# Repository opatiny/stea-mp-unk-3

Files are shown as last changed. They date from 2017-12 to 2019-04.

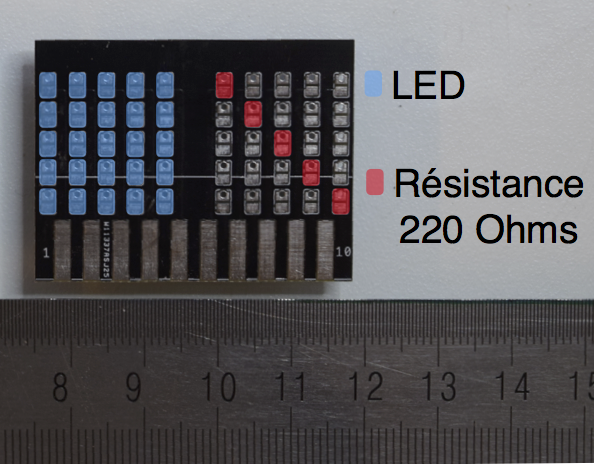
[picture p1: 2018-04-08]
docs/pics/ledMatrixPic.png

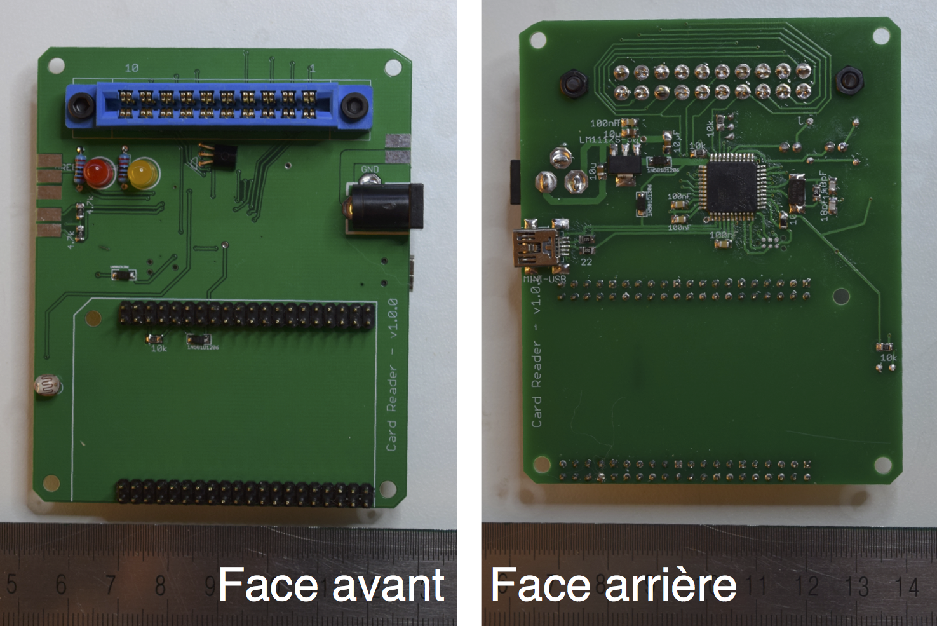
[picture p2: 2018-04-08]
docs/pics/cardReaderPic.png

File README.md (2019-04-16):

# stea-mp-unk-3
## Building an mp3 player in a steampunk style
The goal of this project is to build an autonomous mp3 player contained in an old leather suitcase. It works on batteries, has a 32 characters led display (home-made) and offers an oldschool way to chose the music to play: it uses perforated PCBs with a unique connectivity.

## Results
You can see the final player on this video (in french):
[https://youtu.be/DE0FV9JWbVA](https://youtu.be/DE0FV9JWbVA)

## Documentation
Sadly, the documentation to this project is written in french.
You can find a two-parts description of the project on the following links:

__Frist part: developing and producing the PCBs__

[https://oci.gyre.ch/blog/?post/2018/02/01/18H-patiny](https://oci.gyre.ch/blog/?post/2018/02/01/18H-patiny)

__Second part: finishing the project__

[https://oci.gyre.ch/blog/?post/2017/12/04/18P-patiny](https://oci.gyre.ch/blog/?post/2017/12/04/18P-patiny)

## Programming
All the code related to this project can be found [here](https://github.com/opatiny/node-steam-player).

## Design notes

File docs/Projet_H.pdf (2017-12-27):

# Construction d’un lecteur mp3 steampunk

### Océane Patiny

### 27 décembre 2017

## Description

L’objectif de ce projet est de réaliser un player mp3 dans un style steampunk, qui sera contenu dans une vieille valise. Le produit final sera muni de plusieurs haut-parleurs, d’un affichage LED contrôlé en I2C et il fonctionnera sur batteries. L’écran LED servira à afficher le titre et auteur de la musique ainsi que le temps restant jusqu’à la fin du morceau. La principale particularité sera néanmoins la technique utilisée pour choisir le morceau de musique à jouer. En effet, nous utiliserons des circuits imprimés ayant chacun une connectique unique qui correspond à un morceau. Les cartes devront être placées dans un connecteur de carte enfichable faisant partie d’un module I2C (que nous développerons). Sur ce module, un ATmega32U4 sera alors responsable de vérifier la connectivité. Cela fait, il attribuera celle-ci à un code unique qui pourra être envoyé par I2C à un CHIP. En effet, le micro-contrôleur central de ce projet sera un CHIP, qui est pratique pour sa sortie audio incorporée. Globalement, deux parties hardware devront être développées, étant les deux des modules I2C : premièrement, l’affichage LED, en second lieu, le lecteur de cartes. Ensuite, la partie software permettra le contrôle des modules que nous aurons construits, ainsi que la communication entre ceux-ci et le CHIP.

Élément de l’affichage led

Haut-parleur

PCB de lecture de carte

“Multi-prise”

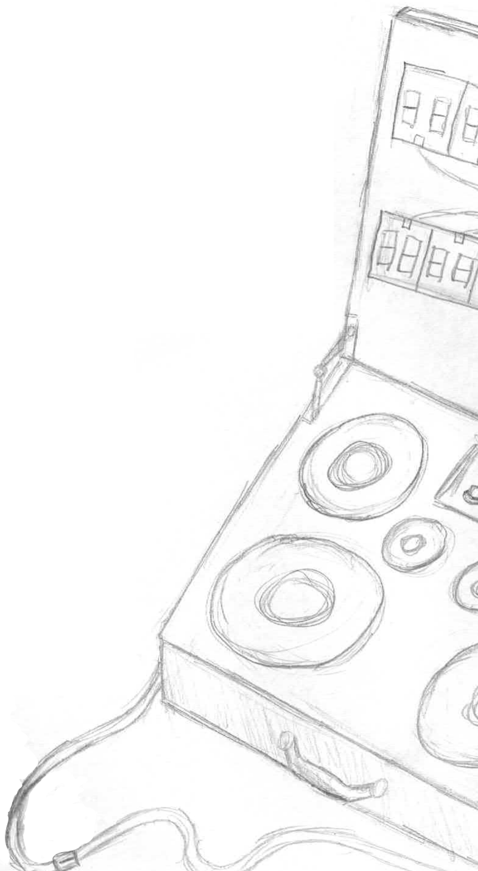
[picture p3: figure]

Figure 1: Schéma global de la valise.

Océane Patiny (3mp2)

## Matériel

Tout le matériel nécessaire à la réalisation de ce projet est listé ci-dessous. Il a été sub-divisé en trois groupes : le matériel que nous avons déjà à disposition, celui qu’il faut acheter et celui qu’il faut construire.

Disponible
— 1 vieille valise en cuir (dimensions intérieures : 450x315x100 mm) — Connecteurs rj12 et câble adapté
— 32 ULN2803
— 9 PCA9685
— 1 ATmega32U4
— 6 haut-parleurs

À se procurer
— 1 bouton rotatif (rotary button) — 1 interrupteur (push button)
— 1 amplificateur
— 7 PCA9685
— 256 résistances de au moins 1 kΩ
— 736 LEDs rouges 5 mm
— 1 connecteur de carte affichable de 10 pôles
— Résistances et condensateurs divers
— 1 batterie de 12 V puissante, par exemple une batterie de mobylette

À réaliser
— 1 PCB lecteur de cartes + bouton de volume + bouton d’allumage
— 16 PCB, chacun de 2 caractères lumineux
— 1 PCB faisant office de multiprise (hub) pour les connecteurs rj12 provenant des cartes de l’affichage LED
— Un modèle de PCB permettant de connecter différentes pattes de sortie de façon unique pour chaque carte. Le nombre de cartes variera en fonction du nombre de morceaux de musique désiré.

## Projet H : Objectifs février

Ce projet sera divisé en deux parties, la première se focalisant sur le hardware et la seconde sur le software. Un premier délai est imposé le 1er février 2018. À cette date, les objectifs suivants devront être remplis :

1. Accumuler le matériel électronique nécessaire à la réalisation du projet.
2. Réaliser des tests permettant de se familiariser avec la sortie son du CHIP.
3. Choisir le matériau à utiliser pour la fixation des hauts-parleurs et de l’affichage LED, acheter des peintures et vis si nécessaire.
4. Réaliser une première version de tous les PCB, les produire et les tester, repérer les bugs à corriger.
5. Choisir le type de support mémoire à utiliser pour stocker la musique.

Pour réussir l’objectif 4, le design des plaques devra être terminé au maximum pendant

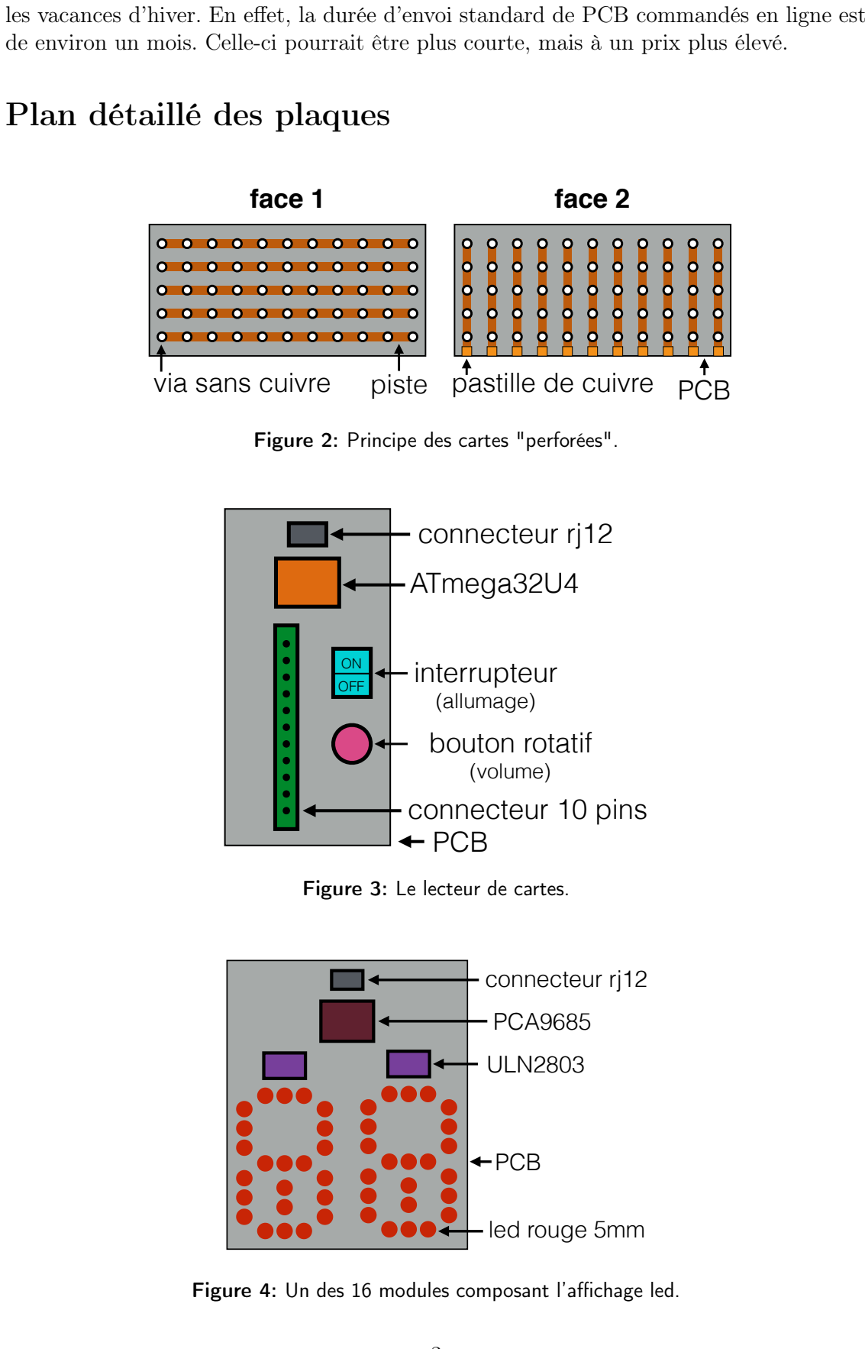
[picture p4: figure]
Plan détaillé des plaques; via sans cuivre; piste; face 1; PCB; face 2; pastille de cuivre; connecteur rj12; ATmega32U4; connecteur 10 pins PCB; OFF; interrupteur; (allumage) bouton rotatif (volume); Figure 3: Le lecteur de cartes.; PCA9685; ULN2803; led rouge 5mm

les vacances d’hiver. En effet, la durée d’envoi standard de PCB commandés en ligne est de environ un mois. Celle-ci pourrait être plus courte, mais à un prix plus élevé.

Figure 2: Principe des cartes "perforées".

Figure 4: Un des 16 modules composant l’affichage led.

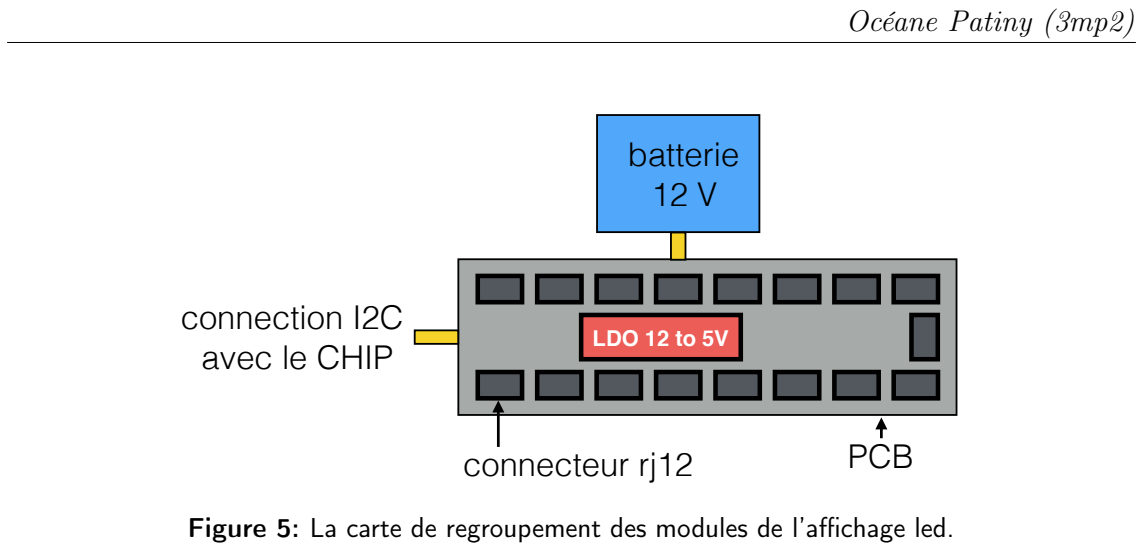
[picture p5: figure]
connection I2C avec le CHIP; batterie 12 V; LDO 12 to 5V; connecteur rj12; PCB

Figure 5: La carte de regroupement des modules de l’affichage led.

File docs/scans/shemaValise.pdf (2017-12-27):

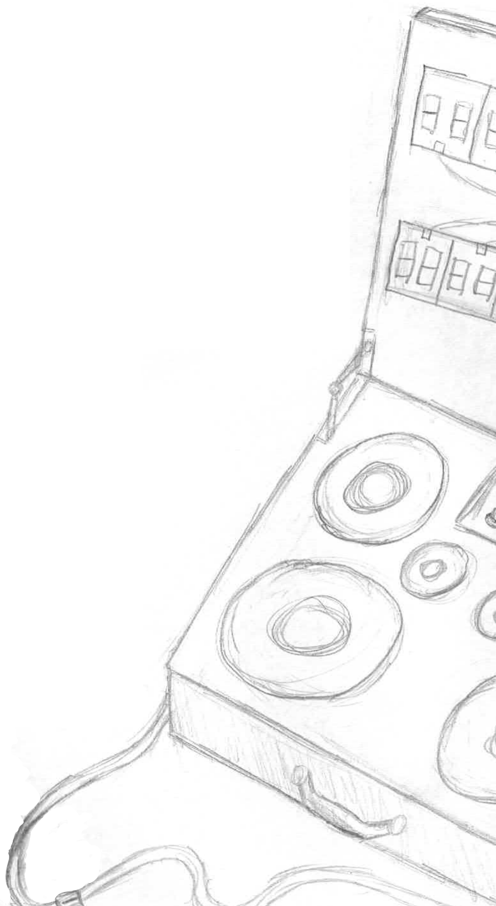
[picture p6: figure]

Élément de l’affichage led

Haut-parleur

PCB de lecture de carte

“Multi-prise”

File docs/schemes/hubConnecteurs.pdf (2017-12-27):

connection I2C
avec le CHIP

batterie
12 V

LDO 12 to 5V

connecteur rj12 | PCB

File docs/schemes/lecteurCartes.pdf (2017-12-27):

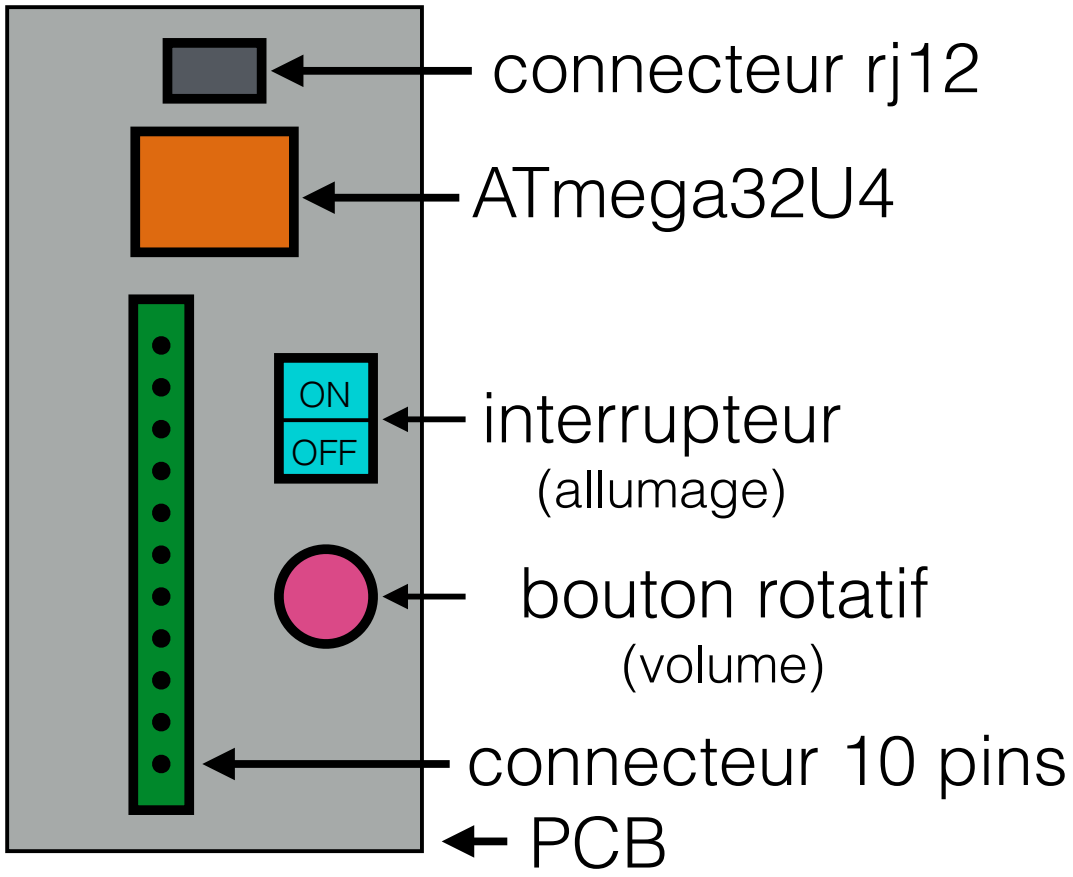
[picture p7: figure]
connecteur rj12; ATmega32U4; connecteur 10 pins PCB; OFF; interrupteur; (allumage) bouton rotatif (volume)

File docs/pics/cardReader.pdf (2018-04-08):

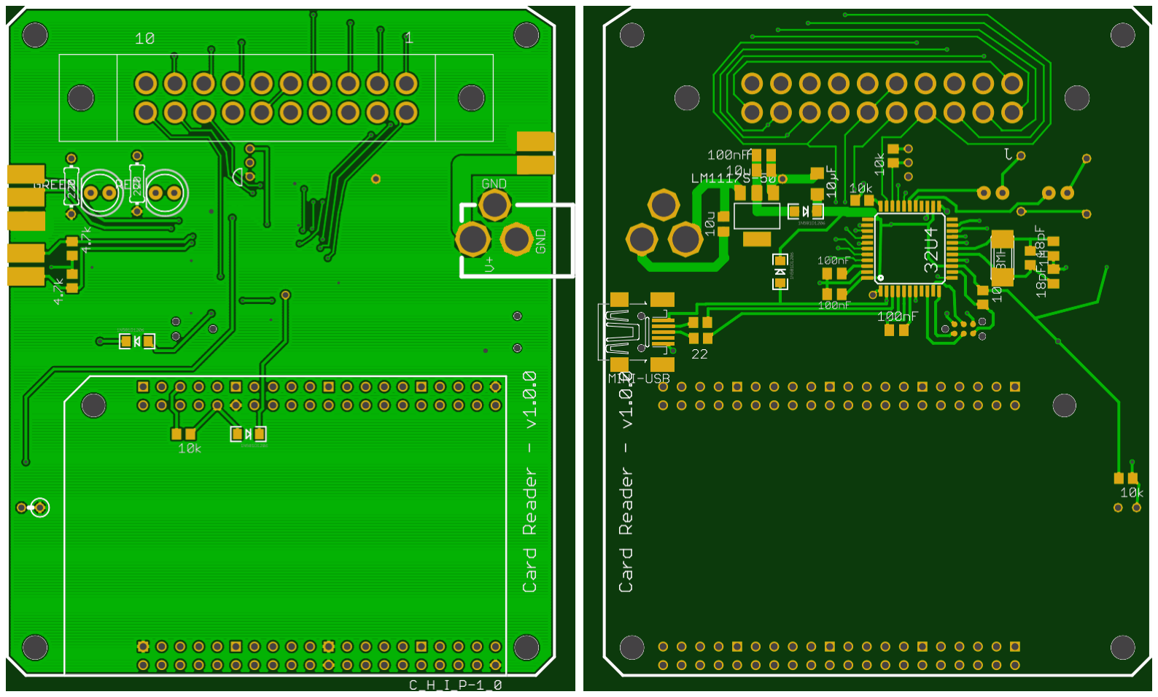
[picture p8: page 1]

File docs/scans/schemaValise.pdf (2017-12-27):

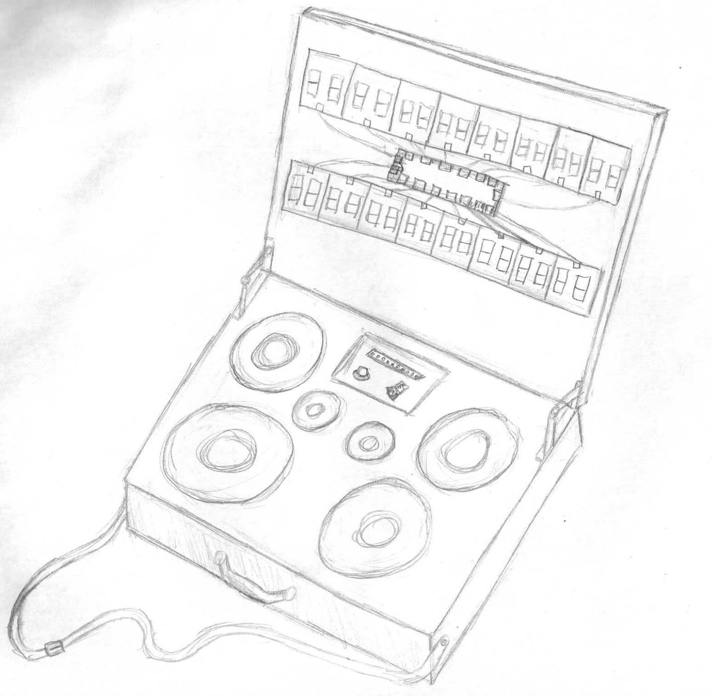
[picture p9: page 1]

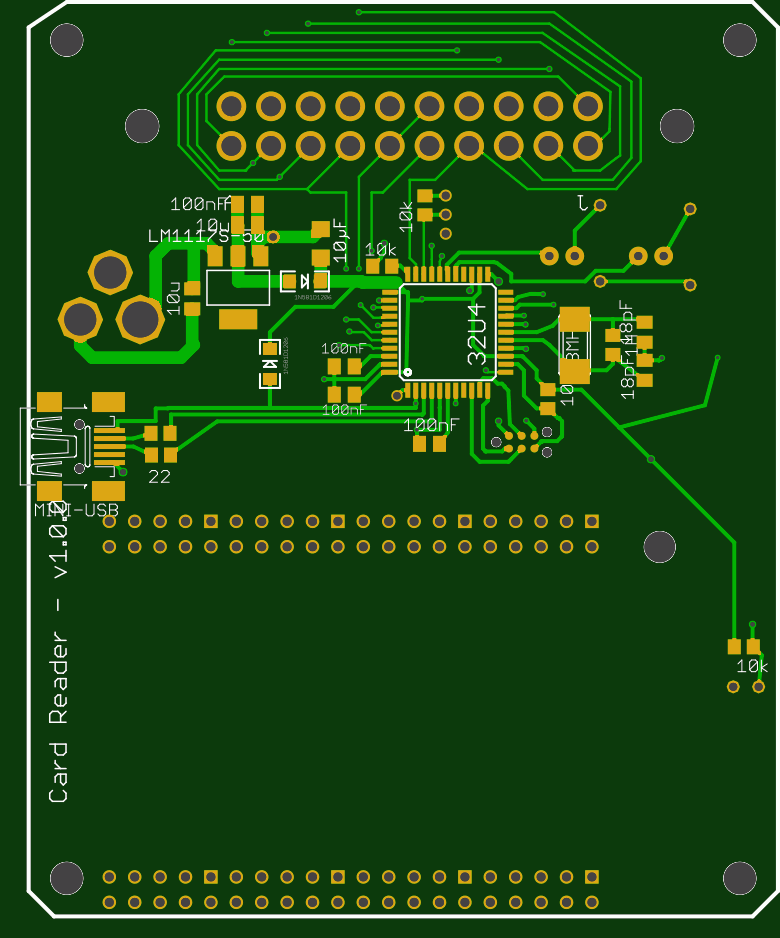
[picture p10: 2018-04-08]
docs/pics/cardReaderBack.png

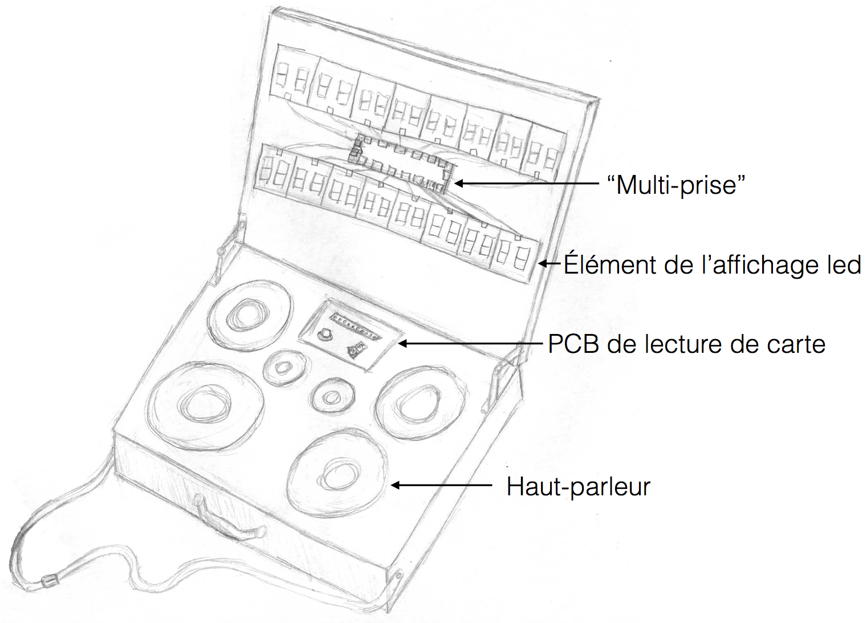
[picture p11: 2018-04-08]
docs/scans/shemaValise.png

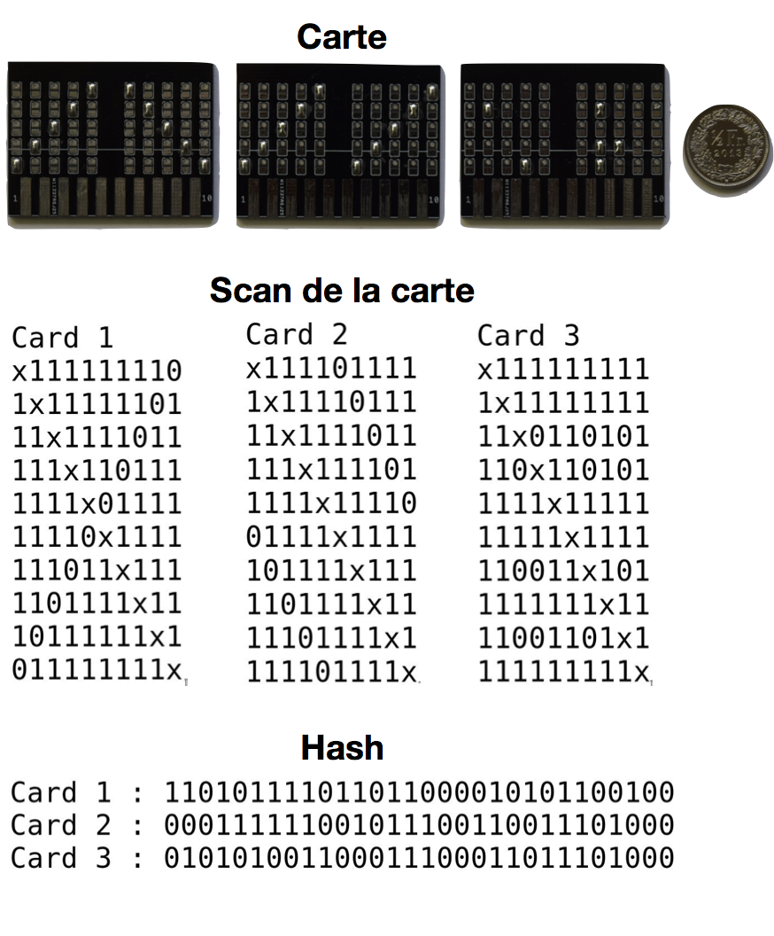
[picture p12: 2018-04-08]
docs/pics/cardScanComparison.png

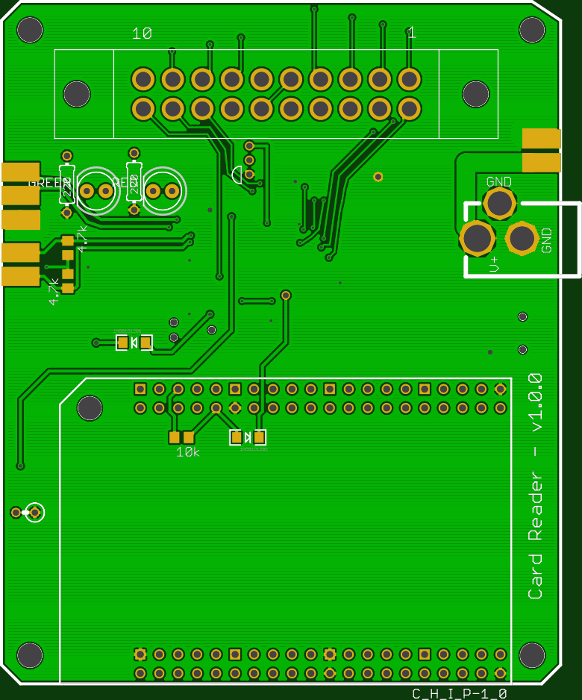
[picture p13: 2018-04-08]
docs/pics/cardReaderBottom.png

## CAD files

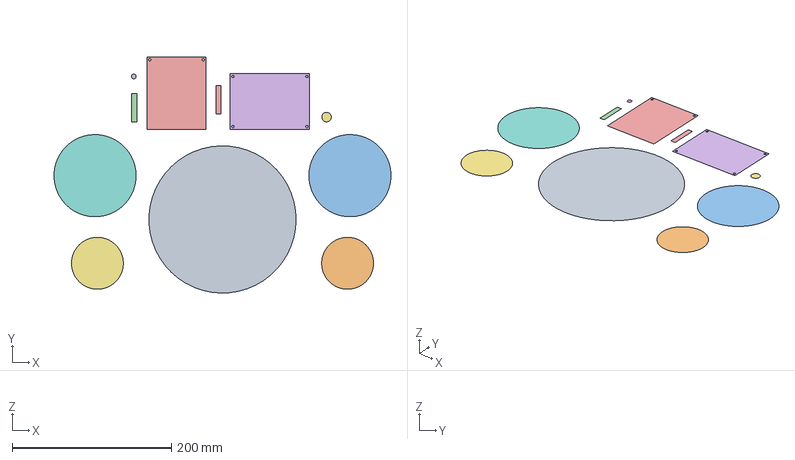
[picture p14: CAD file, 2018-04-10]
freecad/loudspeakerSupport/loudspeakerSupport.fcstd
423.0 x 296.4 x 0 mm
Circle1
Circle2
Circle3
Circle4
cardReader
amplificator
smallLS
mediumLS
largeLS
Mirror of smallLS
Mirror of mediumLS
slot1
slot2
switchHole
jackHole
Circle8
Circle7
Circle6
Circle05

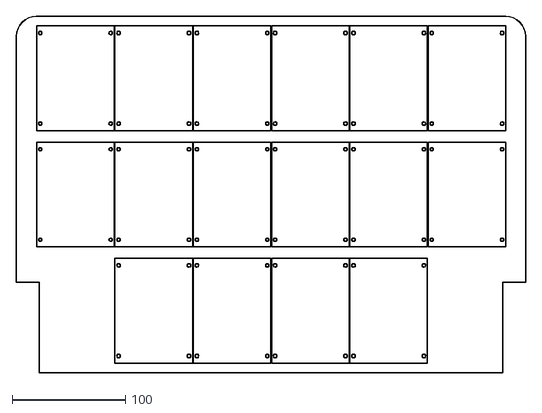
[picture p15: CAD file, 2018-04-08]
freecad/ledDisplaySupport/ledDisplay.dxf
450.0 x 315.0

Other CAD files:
freecad/ledDisplaySupport/ledDisplaySupport.fcstd
freecad/loudspeakerSupport/loudspeakerSupport.dxf

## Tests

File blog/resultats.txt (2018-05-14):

!!!!4. Résultats
Puisque une grande partie des résultats obtenus pour les parties individuelles du projet ont été montrés dans la section __Méthodes__ de ce billet, nous ne montrons ici que les résultats d'ensemble qui sont présentés au travers de la marche à suivre d'utilisation ci-dessous.

!!! Utilisation du lecteur MP3
Voici un court protocole expliquant la procédure qui permet d'utiliser le lecteur MP3. L'équivalent vidéo peut être trouvé au lien suivant : [https://youtu.be/vln9X8TIJ3k].

__Démarrage :__
*Ouvrir la valise en tirant les deux clapets vers l'extérieur après avoir composé le code 197 197. 
*Prendre les six batteries qui se trouvent dans la poche extérieure de la valise et les placer dans les deux portes-batteries en prenant garde au sens.
*Vérifier que tous les fils sont branchés au bon endroit : le câble jack, l'alimentation USB du CHIP, l'alimentation de ''cardReader'' et l'alimentation de l'amplificateur.
*Vérifier que la LED rouge de ''cardReader'' clignote et que la LED verte de l'amplificateur est allumée.
*Patienter le temps du démarrage du CHIP : la LED blanche doit clignoter.
*Lorsque le lecteur est prêt à être utilisé, il affiche ''Waiting'' sur la ligne du haut. Il afficher huit zéro sur celle du bas. Si une carte est insérée et pas reconnue, il affiche le hash correspondant en hexadécimal.

__Utilisation :__
*Balancer le bouton trois positions vers la droite pour mettre en mode 1 (''playlist'') ou le balancer vers la gauche pour mettre en mode 2 (''single song'').
*Prendre la liste des cartes et morceaux correspondants qui se trouve dans la poche extérieure de la valise avec les cartes perforées.
*Insérer une carte perforée dans le lecteur de cartes (les deux sens sont possibles). Le morceau correspondant devrait être joué. Le titre, le nom de l'auteur et le temps restant du morceau sont affichés sur l'afficheur LED.
*En mode 1, autant de cartes que désiré peuvent être insérées, les morceaux correspondants s'ajoutent à la fin de la liste de lecture. Le nombre de morceaux en attente est affiché en bas à droite de l'afficheur LED.
*En mode 2, toute carte insérée interromps la musique jouée et lance le nouveau morceau.

__Arrêt :__
*Placer le bouton trois position en mode 1 et appuyer sur le bouton rouge. La procédure d'arrêt devrait être enclanchée. L'afficheur doit indiquer ''Shutting down''.
*L'appareil est éteint lorsque les LEDs du CHIP sont éteintes.
*Enlever les batteries et les ranger dans la poche extérieure de la valise ainsi que les cartes perforées.
*Refermer la valise en prenant garde à ne pas coincer les quatre fils connectés à l'afficheur LED.

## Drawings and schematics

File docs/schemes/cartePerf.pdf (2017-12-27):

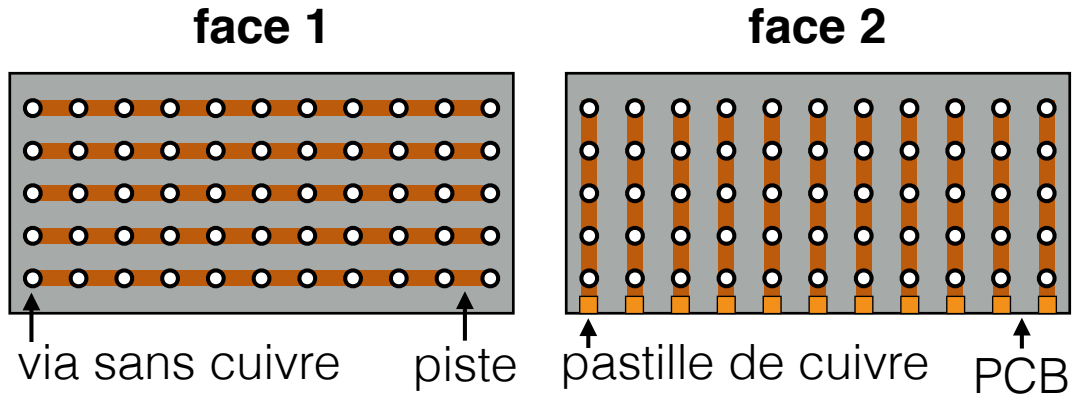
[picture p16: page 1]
via sans cuivre; piste; face 1; PCB; face 2

pastille de cuivre

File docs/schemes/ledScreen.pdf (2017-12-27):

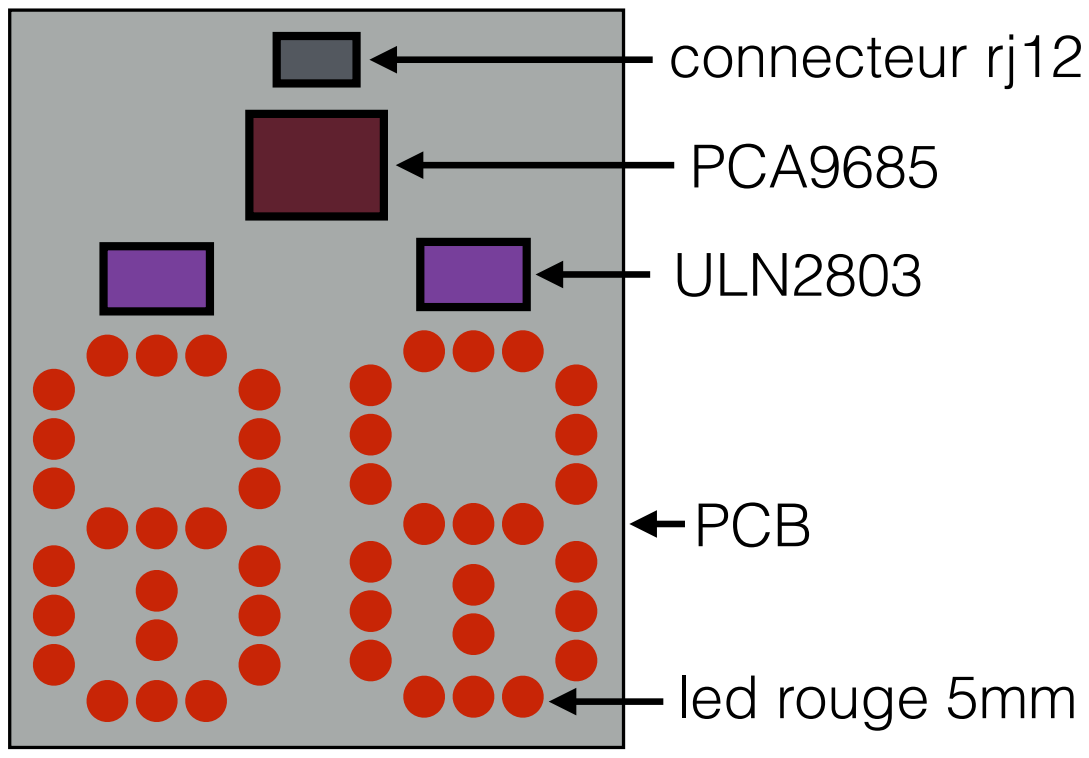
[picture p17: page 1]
connecteur rj12; PCA9685; ULN2803; led rouge 5mm; PCB

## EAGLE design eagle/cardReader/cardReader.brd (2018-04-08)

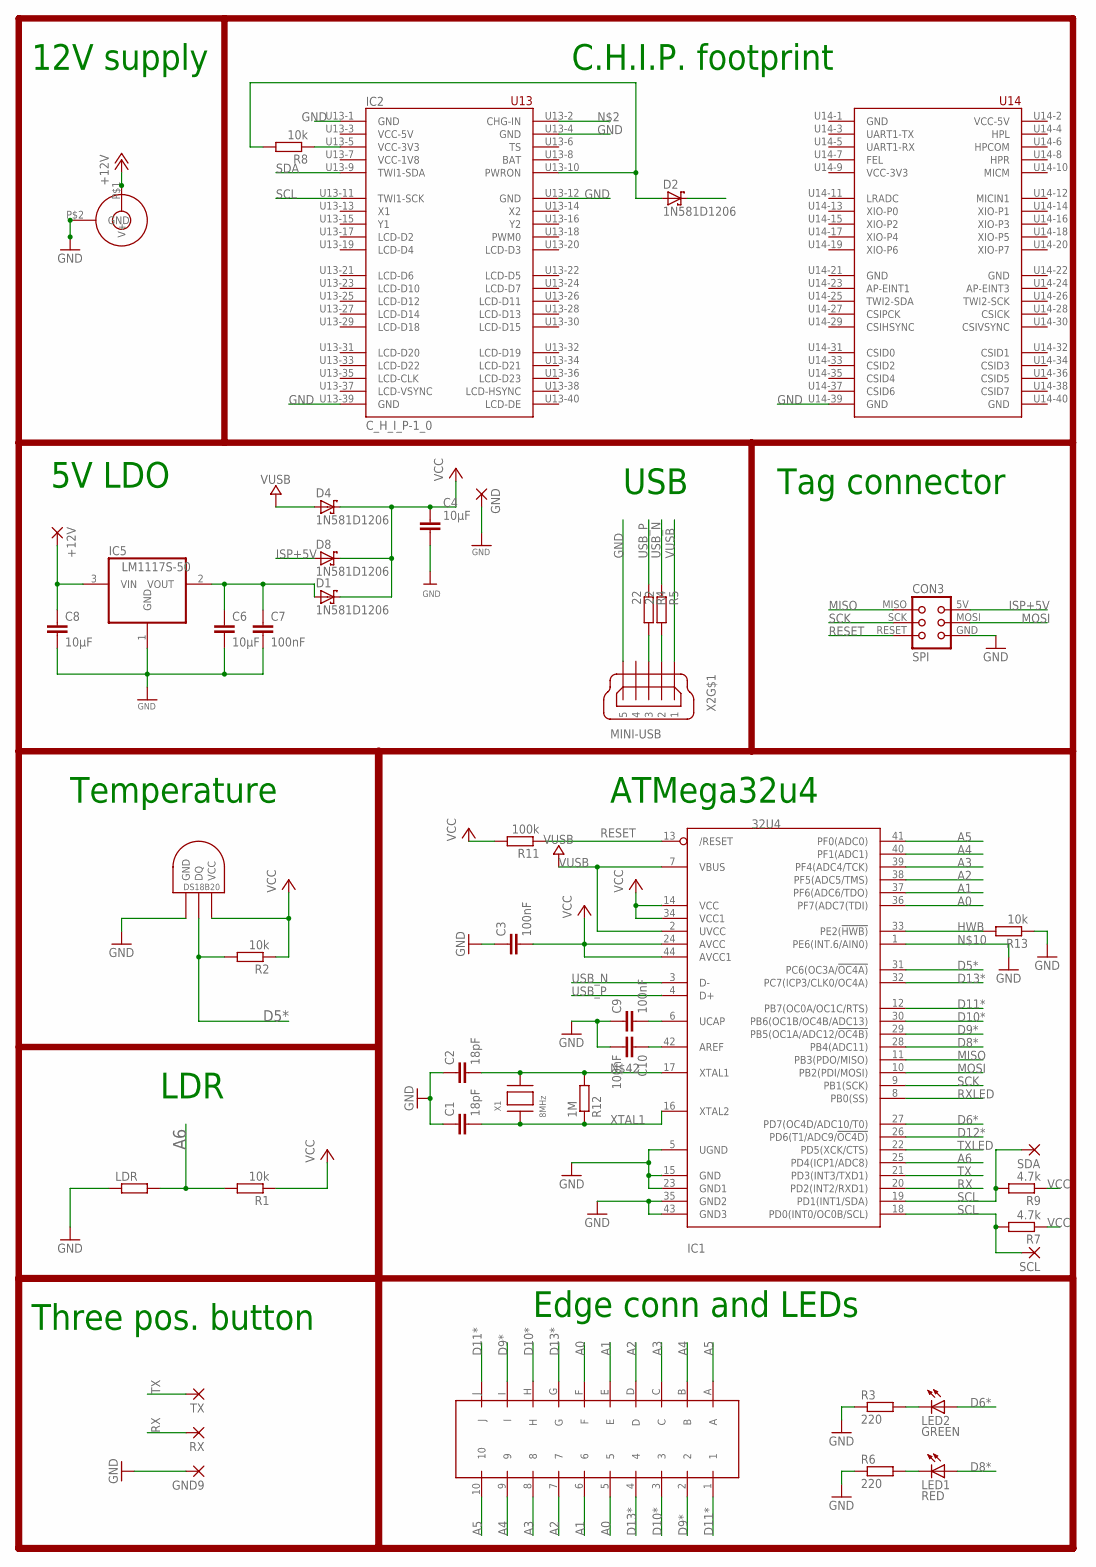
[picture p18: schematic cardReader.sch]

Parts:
+12V: SMD5; SMD2,54-5,08
C1, C2: 18pF; C0805K; MPN 77-VJ1206A180JXXPBC; LCSC C1797
C3, C7, C9, C10: 100nF; C0805K; MPN 80-C1206C104K5R; LCSC C49678
C4: 10µF; C1206
C6, C8: 10µF; C0805K; MPN 77-VJ1206V106ZXQTBC; LCSC C15850
CON2: JACK_DC_BARREL; DC_BARREL
CON3: SPI; TC2030-MCP-NL
D1, D2, D4, D8: 1N581D1206; LED-1206
GND, GND9: SMD5; SMD2,54-5,08
IC1: 32U4; TQFP44; MPN 556-ATMEGA32U4RC-AU; LCSC C44854
IC2: C_H_I_P-1_0
IC5: LM1117S-50; SOT223; LCSC C126027
LDR: R-EU_0207/2V; 0207/2V
LED1: RED; LED5MM
LED2: GREEN; LED5MM
R1, R2, R8: 10k; R0805; MPN RC1206FR-07100KL; LCSC C17407
R3, R6: 220; 0204/7
R4, R5: 22; R0805; LCSC C17561
R7, R9: 4.7k; R0805; MPN RC1206FR-07100KL; LCSC C17407
R11: 100k; R0805; MPN RC1206FR-07100KL; LCSC C17407
R12: 1M; R0805; LCSC C17514
R13: 10k; R0805; LCSC C17414
RX: SMD5; SMD2,54-5,08
SCL: SMD5; SMD2,54-5,08
SDA: SMD5; SMD2,54-5,08
TX: SMD5; SMD2,54-5,08
U$1: DS1820TO92; DS1820
U$3: CONN2X10PRINT
X1: 8MHz; NX6035; MPN 729-F60800010; LCSC C122522
X2: MINI-USB; 32005-201; MPN 649-10033526-N3212LF; LCSC C46391

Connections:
+12V: +12V.1, C8.1, CON2.P$1 (V+), IC5.3 (VIN)
A0: IC1.36 (PF7(ADC7(TDI)), U$3.5, U$3.F
A1: IC1.37 (PF6(ADC6/TDO)), U$3.6, U$3.E
A2: IC1.38 (PF5(ADC5/TMS)), U$3.7, U$3.D
A3: IC1.39 (PF4(ADC4/TCK)), U$3.8, U$3.C
A4: IC1.40 (PF1(ADC1)), U$3.9, U$3.B
A5: IC1.41 (PF0(ADC0)), U$3.10, U$3.A
A6: IC1.25 (PD4(ICP1/ADC8)), LDR.2, R1.2
AREF: C10.1, IC1.42 (AREF)
BAT: IC2.U13-8 (BAT)
D5*: IC1.31 (PC6(OC3A/!OC4A)), R2.2, U$1.DQ
D6*: IC1.27 (PD7(OC4D/ADC10/T0)), LED2.A
D8*: IC1.28 (PB4(ADC11)), LED1.A
D9*: IC1.29 (PB5(OC1A/ADC12/!OC4B)), U$3.2, U$3.I
D10*: IC1.30 (PB6(OC1B/OC4B/ADC13)), U$3.3, U$3.H
D11*: IC1.12 (PB7(OC0A/OC1C/RTS)), U$3.1, U$3.J
D12*: IC1.26 (PD6(T1/ADC9/!OC4D))
D13*: IC1.32 (PC7(ICP3/CLK0/OC4A)), U$3.4, U$3.G
GND: C1.1, C2.1, C3.1, C4.2, C6.2, C7.2, C8.2, C9.1, C10.2, CON2.P$2 (GND), CON3.GND, GND.1, GND9.1, IC1.5 (UGND), IC1.15 (GND), IC1.23 (GND1), IC1.35 (GND2), IC1.43 (GND3), IC2.U13-1 (GND), IC2.U13-4 (GND), IC2.U13-12 (GND), IC2.U13-39 (GND), IC2.U14-1 (GND), IC2.U14-21 (GND), IC2.U14-22 (GND), IC2.U14-39 (GND), IC2.U14-40 (GND), IC5.1 (GND), LDR.1, R3.1, R6.1, R13.1, U$1.GND, X2.5
HWB: IC1.33 (PE2(!HWB)), R13.2
ISP+5V: CON3.5V (VCC), D8.A
MISO: CON3.MISO, IC1.11 (PB3(PDO/MISO))
MOSI: CON3.MOSI, IC1.10 (PB2(PDI/MOSI))
unnamed: C9.2, IC1.6 (UCAP)
unnamed: LED2.K (C), R3.2
unnamed: LED1.K (C), R6.2
unnamed: C6.1, C7.1, D1.A, IC5.2 (VOUT)
unnamed: D2.C, IC1.1 (PE6(INT.6/AIN0))
unnamed: C2.2, IC1.17 (XTAL1), R12.2, X1.P$2
PWRON: D2.A, IC2.U13-10 (PWRON), R8.2
RESET: CON3.RESET, IC1.13 (/RESET), R11.1
RX: IC1.20 (PD2(INT2/RXD1)), RX.1
RXLED: IC1.8 (PB0(SS))
SCK: CON3.SCK, IC1.9 (PB1(SCK))
SCL: IC1.18 (PD0(INT0/OC0B/SCL)), IC2.U13-11 (TWI1-SCK), R7.2, SCL.1
SDA: IC1.19 (PD1(INT1/SDA)), IC2.U13-9 (TWI1-SDA), R9.2, SDA.1
TX: IC1.21 (PD3(INT3/TXD1)), TX.1
TXLED: IC1.22 (PD5(XCK/CTS))
USBC_N: R5.2, X2.2
USBC_P: R4.2, X2.3
USB_N: IC1.3 (D-), R5.1
USB_P: IC1.4 (D+), R4.1
VCC: C3.2, C4.1, D1.C, D4.C, D8.C, IC1.14 (VCC), IC1.24 (AVCC), IC1.34 (VCC1), IC1.44 (AVCC1), R1.1, R2.1, R7.1, R9.1, R11.2, U$1.VDD (VCC)
VCC-3V3@1: IC2.U13-5 (VCC-3V3), R8.1
VUSB: D4.A, IC1.2 (UVCC), IC1.7 (VBUS), X2.1
XTAL1: C1.2, IC1.16 (XTAL2), R12.1, X1.P$1

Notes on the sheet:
USB
ATMega32u4
5V LDO
Temperature
Tag connector
LDR
Three pos. button
Edge conn and LEDs
12V supply
C.H.I.P. footprint

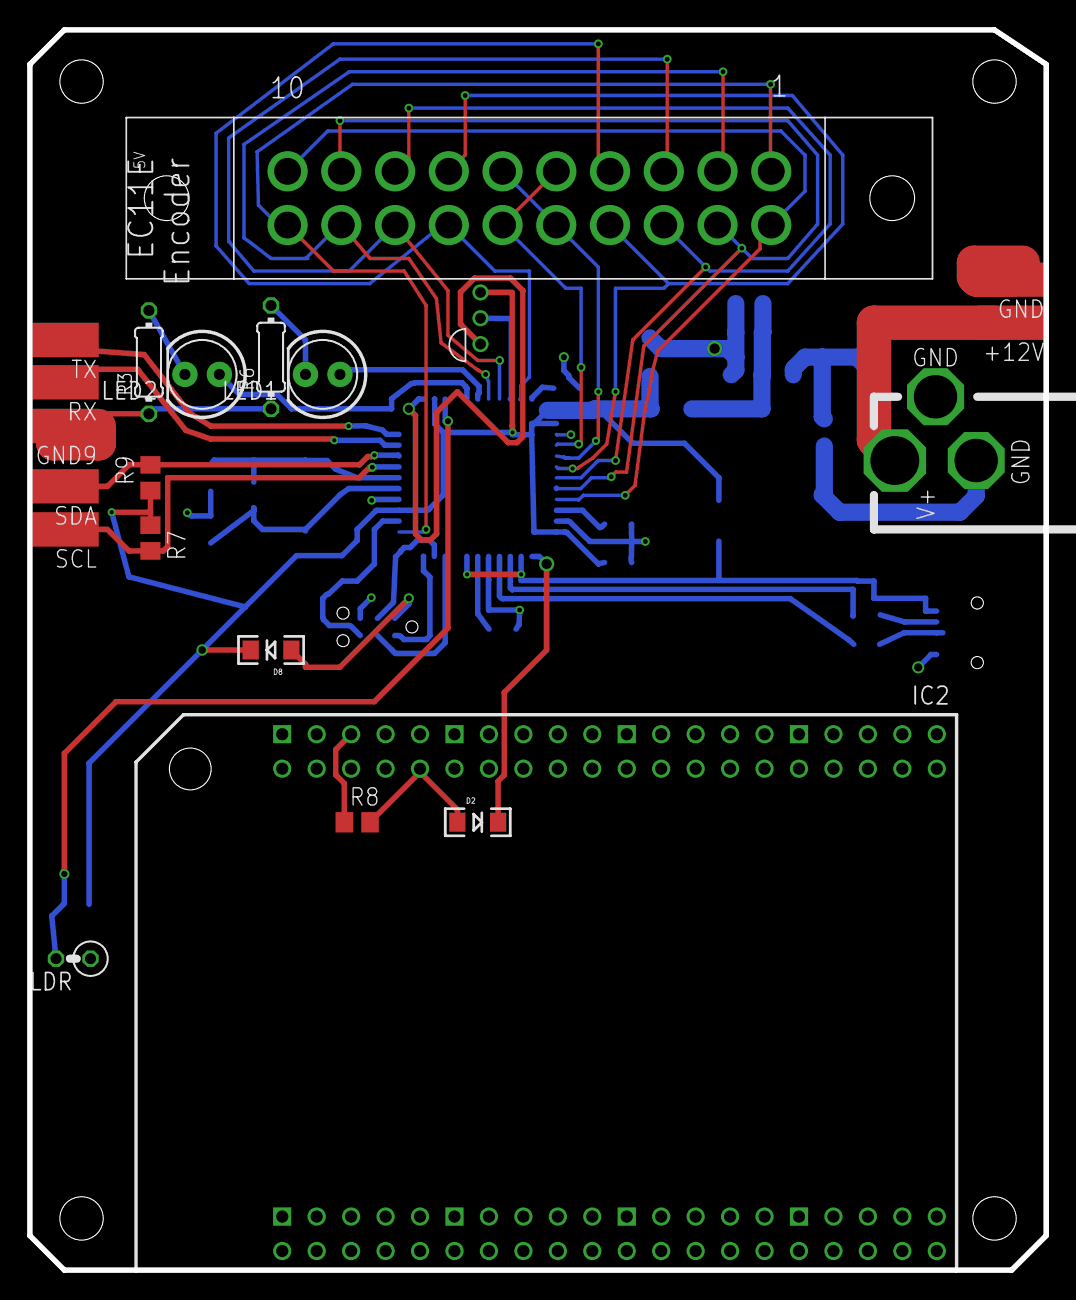
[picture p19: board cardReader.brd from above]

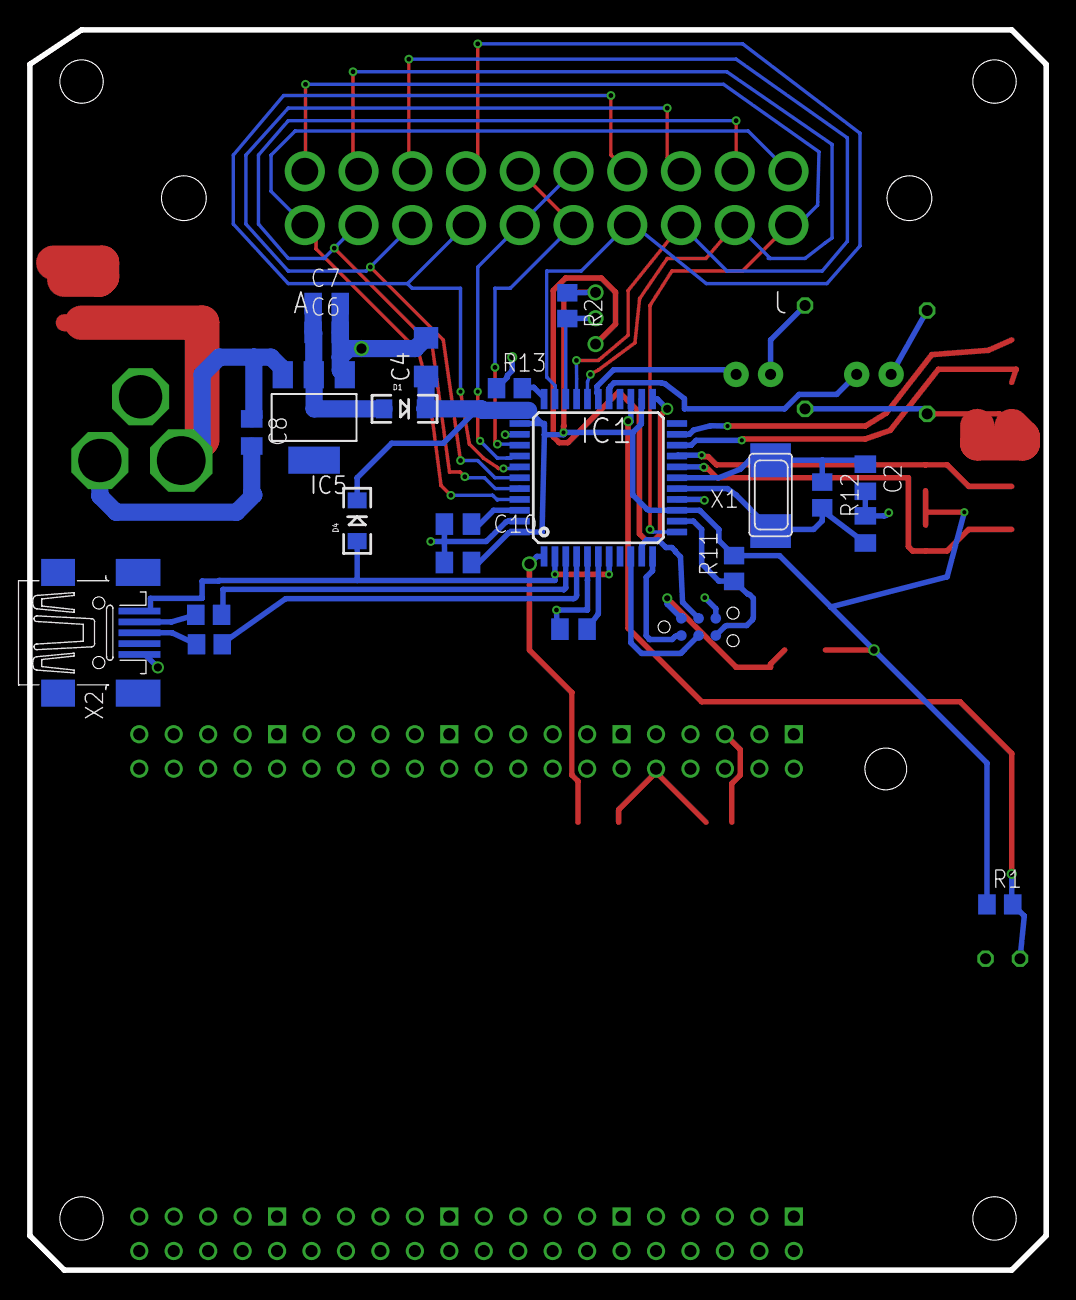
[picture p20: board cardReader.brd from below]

Board: 4 copper layers, 74.9 x 91.4 mm, 44 parts (23 on the bottom side), 42 nets.

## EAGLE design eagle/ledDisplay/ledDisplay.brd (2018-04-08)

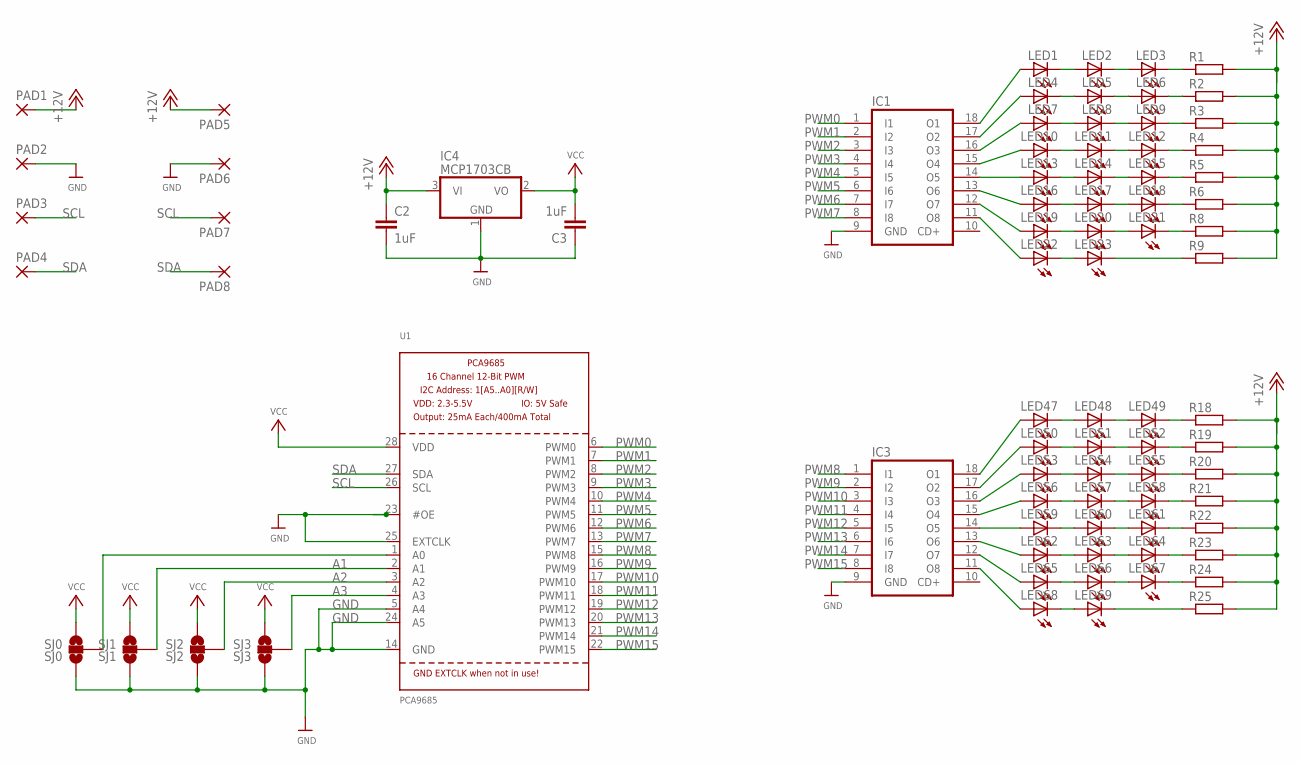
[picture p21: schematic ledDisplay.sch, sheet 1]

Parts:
C2, C3: 1uF; C1206
IC1: ULN2803A; SO18W
IC3: ULN2803AIC; DIL18
IC4: MCP1703CB; SOT23
LED1, LED2, LED3, LED4, LED5, LED6, LED7, LED8, LED9, LED10, LED11, LED12, LED13, LED14, LED15, LED16, LED17, LED18, LED19, LED20, LED21, LED22, LED23, LED47, LED48, LED49, LED50, LED51, LED52, LED53, LED54, LED55, LED56, LED57, LED58, LED59, LED60, LED61, LED62, LED63, LED64, LED65, LED66, LED67, LED68, LED69: LED5MM
PAD1, PAD2, PAD3, PAD4, PAD5, PAD6, PAD7, PAD8: SMD5; SMD2,54-5,08
R1, R2, R3, R4, R5, R6, R8, R9, R18, R19, R20, R21, R22, R23, R24, R25: R-EU_0204/7; 0204/7
SJ0: SJ0; SJ_3
SJ1: SJ1; SJ_3
SJ2: SJ2; SJ_3
SJ3: SJ3; SJ_3
U1: PCA9685; TSSOP28

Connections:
+12V: C2.1, IC4.3 (VI), PAD1.1, PAD5.1, R1.2, R2.2, R3.2, R4.2, R5.2, R6.2, R8.2, R9.2, R18.2, R19.2, R20.2, R21.2, R22.2, R23.2, R24.2, R25.2
A1: SJ1.2, U1.2 (A1)
A2: SJ2.2, U1.3 (A2)
A3: SJ3.2, U1.4 (A3)
GND: C2.2, C3.1, IC1.9 (GND), IC3.9 (GND), IC4.1 (GND), PAD2.1, PAD6.1, SJ0.1, SJ1.1, SJ2.1, SJ3.1, U1.5 (A4), U1.14 (GND), U1.23 (#OE), U1.24 (A5), U1.25 (EXTCLK)
unnamed: LED1.K (C), LED2.A
unnamed: LED2.K (C), LED3.A
unnamed: IC1.18 (O1), LED1.A
unnamed: LED3.K (C), R1.1
unnamed: LED7.K (C), LED8.A
unnamed: LED4.K (C), LED5.A
unnamed: LED5.K (C), LED6.A
unnamed: IC1.17 (O2), LED4.A
unnamed: LED6.K (C), R2.1
unnamed: LED13.K (C), LED14.A
unnamed: LED8.K (C), LED9.A
unnamed: LED9.K (C), R3.1
unnamed: LED14.K (C), LED15.A
unnamed: LED10.K (C), LED11.A
unnamed: LED11.K (C), LED12.A
unnamed: LED12.K (C), R4.1
unnamed: LED15.K (C), R5.1
unnamed: IC1.16 (O3), LED7.A
unnamed: IC1.15 (O4), LED10.A
unnamed: IC1.14 (O5), LED13.A
unnamed: LED16.K (C), LED17.A
unnamed: LED17.K (C), LED18.A
unnamed: LED18.K (C), R6.1
unnamed: IC1.13 (O6), LED16.A
unnamed: LED19.K (C), LED20.A
unnamed: LED20.K (C), LED21.A
unnamed: LED21.K (C), R8.1
unnamed: IC1.12 (O7), LED19.A
unnamed: LED22.K (C), LED23.A
unnamed: LED23.K (C), R9.1
unnamed: IC1.11 (O8), LED22.A
unnamed: LED47.K (C), LED48.A
unnamed: SJ0.2, U1.1 (A0)
unnamed: LED48.K (C), LED49.A
unnamed: IC3.18 (O1), LED47.A
unnamed: LED49.K (C), R18.1
unnamed: LED50.K (C), LED51.A
unnamed: LED51.K (C), LED52.A
unnamed: IC3.17 (O2), LED50.A
unnamed: LED52.K (C), R19.1
unnamed: LED53.K (C), LED54.A
unnamed: LED54.K (C), LED55.A
unnamed: LED55.K (C), R20.1
unnamed: LED56.K (C), LED57.A
unnamed: LED57.K (C), LED58.A
unnamed: LED58.K (C), R21.1
unnamed: IC3.16 (O3), LED53.A
unnamed: IC3.15 (O4), LED56.A
unnamed: LED59.K (C), LED60.A
unnamed: LED60.K (C), LED61.A
unnamed: LED61.K (C), R22.1
unnamed: LED62.K (C), LED63.A
unnamed: LED63.K (C), LED64.A
unnamed: LED64.K (C), R23.1
unnamed: IC3.14 (O5), LED59.A
unnamed: IC3.13 (O6), LED62.A
unnamed: LED65.K (C), LED66.A
unnamed: LED66.K (C), LED67.A
unnamed: LED67.K (C), R24.1
unnamed: LED68.K (C), LED69.A
unnamed: IC3.12 (O7), LED65.A
unnamed: IC3.11 (O8), LED68.A
unnamed: LED69.K (C), R25.1
PWM0: IC1.1 (I1), U1.6 (PWM0)
PWM1: IC1.2 (I2), U1.7 (PWM1)
PWM2: IC1.3 (I3), U1.8 (PWM2)
PWM3: IC1.4 (I4), U1.9 (PWM3)
PWM4: IC1.5 (I5), U1.10 (PWM4)
PWM5: IC1.6 (I6), U1.11 (PWM5)
PWM6: IC1.7 (I7), U1.12 (PWM6)
PWM7: IC1.8 (I8), U1.13 (PWM7)
PWM8: IC3.1 (I1), U1.15 (PWM8)
PWM9: IC3.2 (I2), U1.16 (PWM9)
PWM10: IC3.3 (I3), U1.17 (PWM10)
PWM11: IC3.4 (I4), U1.18 (PWM11)
PWM12: IC3.5 (I5), U1.19 (PWM12)
PWM13: IC3.6 (I6), U1.20 (PWM13)
PWM14: IC3.7 (I7), U1.21 (PWM14)
PWM15: IC3.8 (I8), U1.22 (PWM15)
SCL: PAD3.1, PAD7.1, U1.26 (SCL)
SDA: PAD4.1, PAD8.1, U1.27 (SDA)
VCC: C3.2, IC4.2 (VO), SJ0.3, SJ1.3, SJ2.3, SJ3.3, U1.28 (VDD)

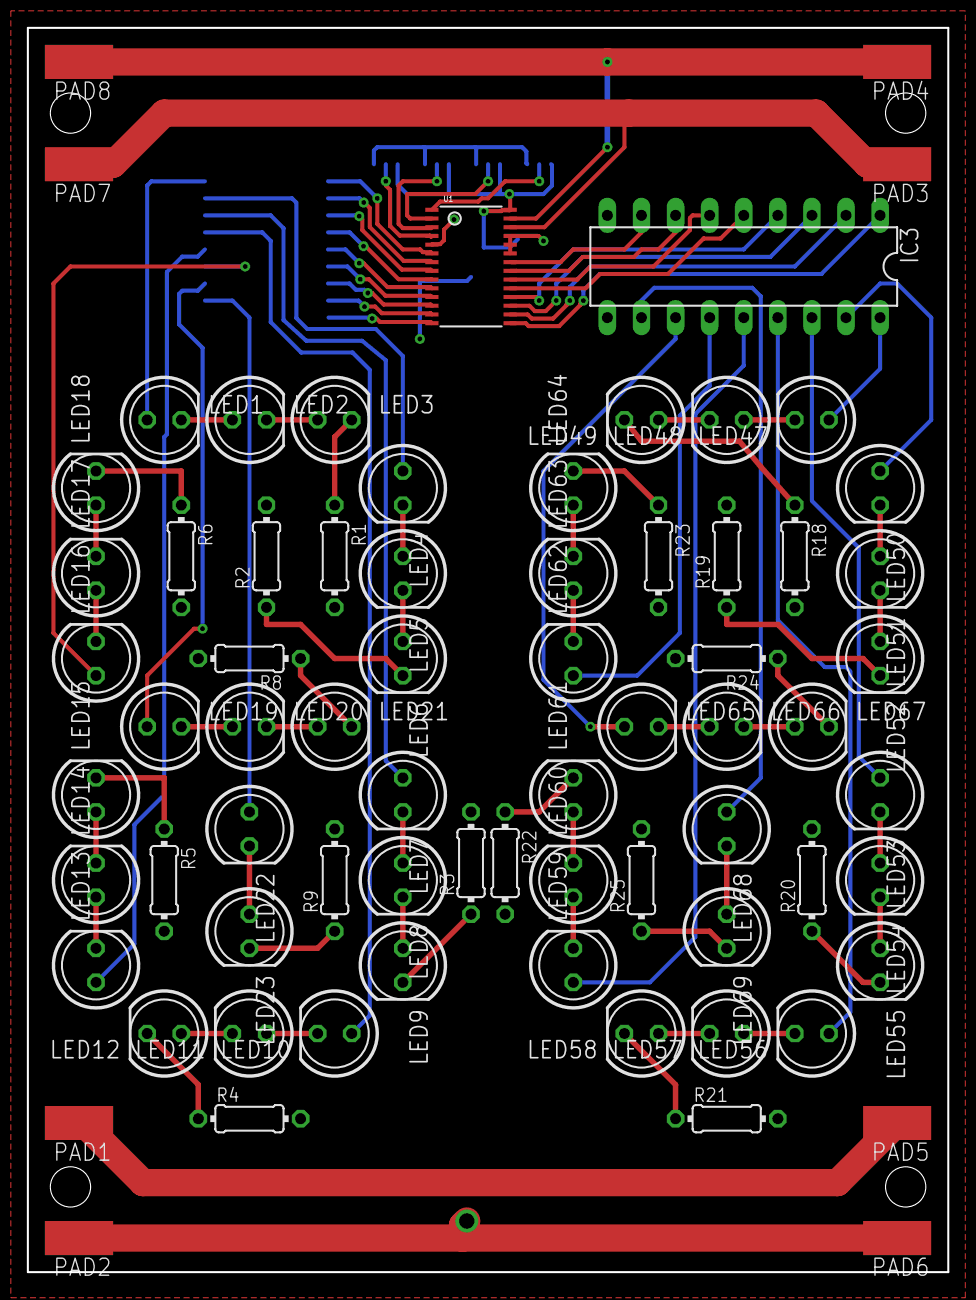
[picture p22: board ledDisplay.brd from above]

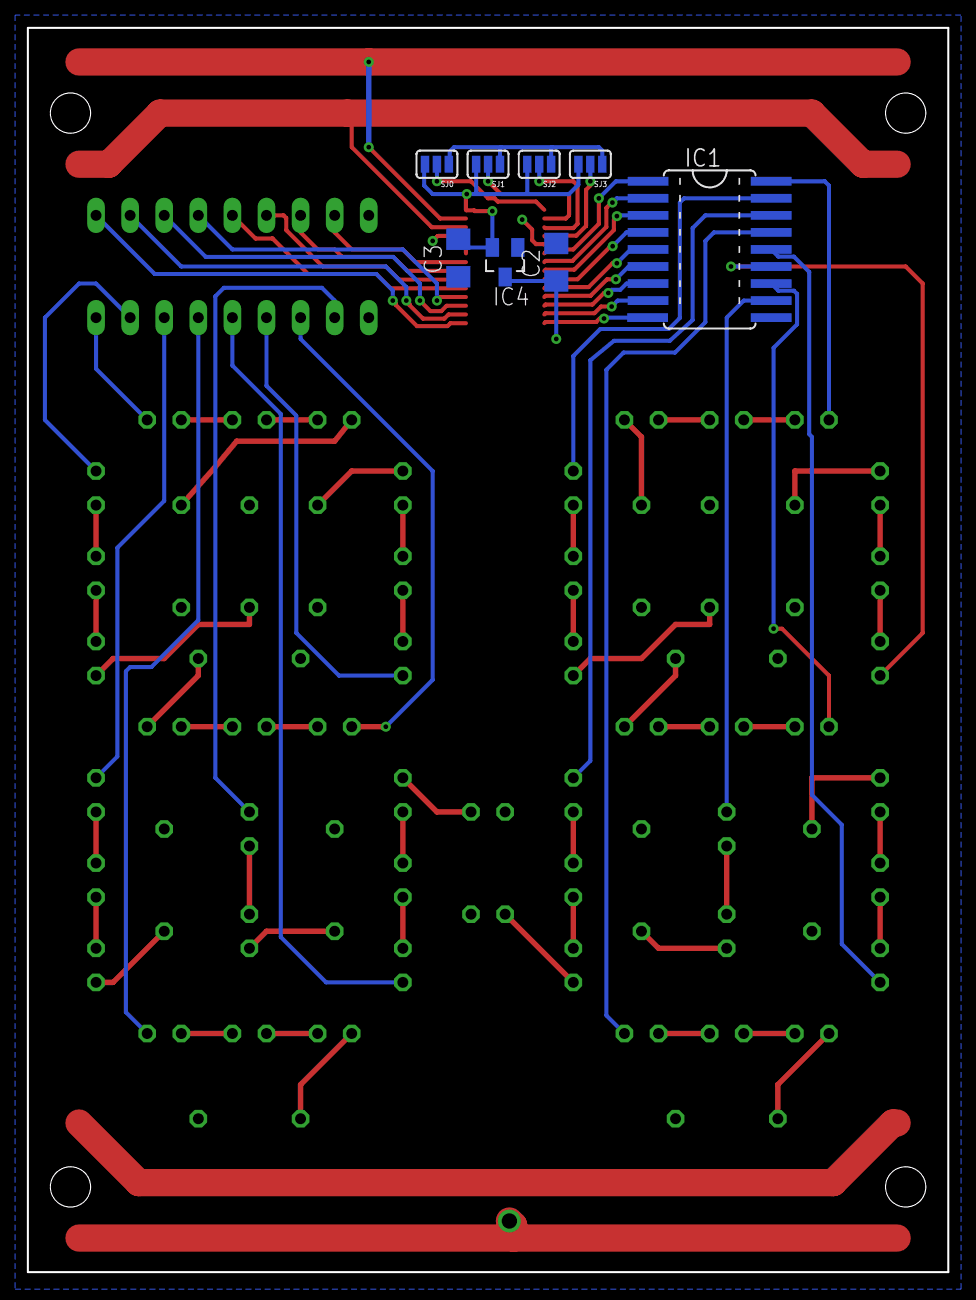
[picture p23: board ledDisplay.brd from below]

Board: 2 copper layers, 68.6 x 92.7 mm, 80 parts (8 on the bottom side), 87 nets.

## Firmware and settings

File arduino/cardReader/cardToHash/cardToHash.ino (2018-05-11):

// based on https://gist.github.com/badboy/6267743
// returns 32 bits hash of perf card connections, highly likely unique
// code is based on arduino/cardscan and arduino/testHash

#define RED_LED 6
#define GREEN_LED 8

void setup() {
  Serial.begin(9600);

}


void loop() {
  byte connPins[] = {A5, A4, A3, A2, A1, A0, 13, 10, 9, 11}; // from 10 to 1

  pinMode(RED_LED, OUTPUT);
  pinMode(GREEN_LED, OUTPUT);

  long previousKey = 0;

  long key = 0;

  for (byte i = 0; i < sizeof(connPins); i++) {
    digitalWrite(RED_LED, !digitalRead(RED_LED));
    delay(30);
    for (byte j = 0; j < sizeof(connPins); j++) {
      pinMode(connPins[j], INPUT_PULLUP); // to avoid floating pins
    }
    pinMode(connPins[i], OUTPUT);
    digitalWrite(connPins[i], LOW);

    for (byte j = 0; j < sizeof(connPins); j++) {
      if (i != j) {
        key ^= digitalRead(connPins[j]) << j;
      }
    }

    key = hash32shift(key);
  }

  key ^= 0b1010001001111010001000110111111; // key obtained when no card is inserted, we use a xor to turn this value to zero (easier to recognise)

  if (previousKey != key) {
    Serial.println(key, HEX);
  }

  delay(1000);
}


long hash32shift(long key) {
  key = ~key + (key << 15); // key = (key << 15) - key - 1;
  key = key ^ (key >> 12);
  key = key + (key << 2);
  key = key ^ (key >> 4);
  key = key * 2057 + (key << 3) + (key << 11);
  key = key ^ (key >> 16);
  return key;
}

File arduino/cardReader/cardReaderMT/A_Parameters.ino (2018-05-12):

// code based on https://github.com/Hackuarium/simple-spectro/tree/master/arduino/SimpleSpectro. Setting parameters required by the CHIP.
/*********************************************
   This file is used to declare the parameters
   table used by the program.

   We use the EEPROM for saving the parameters
   changed by the user during the functionment
   of the Bioreactor.

   The parameters are loaded during the boot.

   All important changes made on a parameter are saved
   in the EEPROM.
 *********************************************/


#define MAX_PARAM 26   // If the MAX_PARAM change you need to change the pointer in the EEPROM


#define PARAM_LUMINOSITY   0
#define PARAM_TEMPERATURE  1
#define PARAM_MODE         2 // mode selected with button position (off, playlist and single song)
#define PARAM_LED_1        3
#define PARAM_LED_2        4
#define PARAM_SCAN_1       5 // hash is returned on 2 16 bits binaries. -> scan 1 and 2
#define PARAM_SCAN_2       6
#define PARAM_SCAN_ENABLED 7


#define INT_MAX_VALUE       32767
#define LONG_MAX_VALUE      2147483647


void resetParameters() { // turn all parameters to 0
  for (byte i = 0; i < 10; i++) {
    setAndSaveParameter(i, 0);
  }

  setQualifier(32767);
}

void checkParameters() {
    if (getParameter(PARAM_LUMINOSITY) < 0) {
    resetParameters();
  }
}

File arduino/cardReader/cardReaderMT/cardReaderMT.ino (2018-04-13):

// including libraries, defining main pins used and setting up general setup and loop.

#include <NilRTOS.h>
#include <avr/wdt.h> // watch dog for automatic reboot in case of crash
#include <TimeLib.h> // git clone https://github.com/PaulStoffregen/Time
#include "lib/Utility.h"


// setting sensors pins
#define LUMINOSITY    A6
#define TEMPERATURE   5

#define CARD_READER   1
#define WIRE_SLAVE    8 // address of the I2C slave

// defining LEDs pins
#define RED_LED       6
#define GREEN_LED     8

// defining button pins
#define BUTTON_1      0
#define BUTTON_2      1


void setup() {
  setupParameters();
  checkParameters(); // setup automatically the default parameter after install boot loader
#ifdef WIRE_SLAVE
  startWireSlave();
#endif
  nilSysBegin();
}

void loop() {}

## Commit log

2017-12-27 v. 1.0 of led display board and docs folder
    [ledDisplay.brd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]
2017-12-31 add arduino files to test led display pcb
2017-12-31 work on freecad files
    [ledDisplay.dxf, ledDisplaySupport.fcstd]
2018-01-01 add v. 1.0 of perfCard
    [perfCard.brd, perfCard.sch]
2018-03-17 hole git (feat): synced github with school server
    [CHIP_1_0.brd, CHIP_1_0.sch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]
2018-04-08 feat (arduino): i2c_scanner changed
2018-04-08 feat (arduino): minor changes in cardScan and cardScanWithLed
2018-04-08 add the required arduino libraries
2018-04-08 move cardReaderMT and add i2c slave
2018-04-09 feat (arduino): add multiThread and work on cardReaderMT
2018-04-10 feat (arduino): add comments to cardReaderMT
    [ledDisplay.dxf, ledDisplaySupport.fcstd]
2018-04-10 fix (freecad): commit problems and add loudspeakerSupport
    [ledDisplay.dxf, ledDisplaySupport.fcstd, loudspeakerSupport.fcstd]
2018-04-11 feat (arduino): comments to cardReaderMT and add buttontest and squaresOnMatrix2
2018-04-11 add (freecad): loudspeakerSupport.dxf
    [loudspeakerSupport.dxf]
2018-04-11 feat (arduino): work on button interaction
2018-04-13 feat (arduino): work on ledDisplay
2018-04-13 feat (arduino): add button thread to cardReaderMT
2018-04-13 fix blinking and delay
    [Animation.ino, CardReader.ino, Z_Start_thread.ino]
2018-04-15 fix parameter name and byte order for card ID
    [A_Parameters.ino, CardReader.ino]
2018-04-18 feat (arduino): add testWakeUp
2018-04-22 feat (eagle): update perfCard and add cam processor
    [perfCard.brd]
2018-04-28 feat (arduino/cardReader): add animation for rainbow card
2018-04-28 feat (arduino/cardReaderMT): fix rainbow animation
    [Animation.ino]
2018-05-10 feat (arduino): modify ledDisplay tests
2018-05-12 feat (arduino): fix button thread for CHIP shutdown
    [A_EEPROM.ino, A_Parameters.ino, Button.ino]
2018-05-12 fix buttons
2018-05-13 feat (arduino): remove space

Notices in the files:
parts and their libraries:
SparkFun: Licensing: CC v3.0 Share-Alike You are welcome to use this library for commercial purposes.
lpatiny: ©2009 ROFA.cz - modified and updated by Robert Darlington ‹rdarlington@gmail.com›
